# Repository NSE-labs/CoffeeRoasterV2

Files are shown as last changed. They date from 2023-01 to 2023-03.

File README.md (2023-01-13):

# CoffeeRoasterV2

This project is a redesign of the coffee roaster controls that were implemented over a decade ago. In that previous design, the low level control circuits were installed within the coffee roaster itself. Years of operation in the elevated temperatures combined with dust from the roasting process have made maintenance of the circuits difficult at best, not to mention the tight fit of these circuits within the roaster.

For more information, check out the Documentation directory of this project.

Note that the Node Red software for this project resides in a separate GitHub repository (*CoffeeRoasterV2NodeRed*). This allows use of the Node Red Project feature to manage the Node Red code through Git/Github. The Git repository for that code resides on the Atomic Pi and so is separate from this repository.

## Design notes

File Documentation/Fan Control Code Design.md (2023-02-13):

# Arduino code design for fan control
## Overview
The main fan on the coffee roaster is driven by a triac circuit that is controlled by the Arduino software to vary the speed of the fan, based on the user-controlled fan setting (0-100%). In the original version of the coffee roaster controls the heater was also controlled this way, but in Version 2 the heater is now controlled by a Solid State Relay.

There are two signal lines between the triac circuit and the Arduino processor, Zero Crossing Detect and Trigger Triac.
```mermaid
sequenceDiagram
    Triac Circuit->>Processor: Zero Crossing Detect
    Processor->>Triac Circuit: Trigger Triac
```
The Zero Crossing Detect is driven by the AC line voltage going to the triac circuit. The AC line voltage is a sine wave with a frequency of 60 Hz in North America. Each time the voltage passes through zero (each half cycle of the sine wave) the Zero Crossing Detect signal is triggered. When the processor sees this signal it starts a count which is based on the fan setting (0-100%). When the count expires the processor pulses the Trigger Triac signal which turns the triac on, thus supplying voltage and current to the fan motor. Once the triac is triggered it will stay latched on until the AC line voltage reaches zero again - the next zero crossing (that's just the way triacs work - once triggered they stay on until the supply voltage goes to zero). The longer the delay (up to one half cycle) between Zero Crossing Detect and Trigger Triac, the less of each AC cycle will be supplied to the fan motor, and the slower it will go. This is repeated each half cycle of the AC line voltage, or 120 times per second.
## Details of the implementation
The Arduino processor (Atmel ATmega328) has a number of built-in hardware features in addition to the processor core. This includes
- The ability for an external signal to interrupt the software execution and cause it to vector to an interrupt service routine (external interrupt).
- A 16-bit timer/counter (Timer 1) with two compare registers that can be used to drive an external signal when the timer reaches the count loaded into the compare register.

The triac circuit is connected to the processor as follows:

|Signal|Pin Direction|Arduino Pin|Processor Pin|Function|
|-|:-:|:-:|:-:|-|
|Zero Crossing Detect|Input|D2|PD2|External Interrupt 0 (INT0)|
|Trigger Triac|Output|D9|PB1|Timer/Counter1 output compare match A output (OC1A)|
| | | | | |

Timer 1 is initialized as listed in the following table. Please refer to the [ATmega328 datasheet](https://ww1.microchip.com/downloads/en/DeviceDoc/Atmel-7810-Automotive-Microcontrollers-ATmega328P_Datasheet.pdf) for a thorough description of the Timer 1 registers.
|Register|Value|Setting|
|-|-|-|
|TCCR1A|B01000000|Trigger Triac (OC1A) signal toggles on comparator match, timer set to normal counting mode (not PWM). The initialization code also ensures that the OC1A output signal is initialized to zero (logic low).|
|TCCR1B|B00000010|No capture filtering (input capture isn't used in this design), timer set to normal counting mode (not PWM), the clock prescaler is set to clk/8. The Arduino system clock frequency is 16 MHz so in this case the timer clock is set to 16 MHz/8 = 2 MHz or 0.5 microseconds per count.|
|TIMSK1|B00000010|Compare A interrupt enabled. An interrupt will occur when the timer reaches the value in the compare register (OCR1A).|
| | | 

The sequence of operation is as follows:
1. When a zero crossing is detected the External Interrupt 0 (Zero Crossing Detect) interrupt service routine sets the timer count (TCNT1) register to zero and sets the output compare register (OCR1A) to the target timer count at which it will turn on the Trigger Triac signal and cause an interrupt. It gets this target timer count from a lookup table where the index is the desired fan setting (0-100%) and the output is the target count.
2. The timer then counts up at 0.5 microseconds per count until it reaches the target value stored in the compare register (OCR1A). This causes the Trigger Triac (OC1A) signal to turn on (logic high) and the timer compare A interrupt to occur.
3. The timer compare A interrupt service routine waits for a brief period to provide the minimum pulse width to trigger the triac, then turns off the Trigger Triac signal (logic low). The cycle then repeats at step 1.

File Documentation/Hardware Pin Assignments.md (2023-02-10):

# NSE Coffee Roaster V2
## Hardware Pin Assignments
----
### Arduino Nano
| Digital Pin | Connection | I/O |
| --- | --- | --- |
| 0 | Serial Receive Data | Input |
| 1 | Serial Transmit Data | Output |
| 2 | Zero Crossing Detect (INT0) | Input |
| 3 | Roaster Drum Motor On/Off | Output |
| 4 | Roaster Case Fan On/Off | Output |
| 5 | MAX 6675 D0 | Input |
| 6 | MAX 6675 CS | Output |
| 7 | MAX 6675 CLK | Output |
| 8 | Open | |
| 9 | Fan Triac Trigger | Output |
| 10 | Heater SSR On/OFF | Output |
| 11 | Front Panel LED - Manual | Output |
| 12 | Front Panel LED - Computer | Output |
| 13 | On-board LED | Output |

| Analog Pin | Connection | I/O |
| --- | --- | --- |
| A0 | Heater Front Panel Pot | Input |
| A1 | Fan Front Panel Pot | Input |
| A3 | Open | |
| A4 | I2C Display Interface | Output |
| A5 | I2C Display Interface | Output |
----
### Front Panel Interface Ribbon Cable
| Cable Pin | Signal |
| --- | --- |
| 1 | VCC (+5V) |
| 2 | Ground |
| 3 | Display Pin 4 |
| 4 | Display Pin 3 |
| 5 | Heater Pot |
| 6 | Fan Pot |
| 7 | NC |
| 8 | LED - Manual |
| 9 | NC |
| 10 | LED - Computer |

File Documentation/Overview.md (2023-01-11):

# Coffee Roaster V2
## Background
This project is a redesign of the coffee roaster controls that were implemented over a decade ago. In that previous design, the low level control circuits were installed within the coffee roaster itself. Years of operation in the elevated temperatures combined with dust from the roasting process have made maintenance of the circuits difficult at best, not to mention the tight fit of these circuits within the roaster.

## Project Goals
The idea for this project is to move all of the control circuitry to an external enclosure, and to update where it makes sense to more modern components. Adding a built-in touch panel display to do the high level control functions is also desirable.

## Design

The first challenge this presents is the interface between the coffee roaster and the external enclosure. There are several high voltage and in some cases high current connections that need to be made. Obviously it would be good to keep this interface as simple as possible and not have a multitude of connections to make between the roaster and the electronics enclosure. Luckily a connector set was found at the Huntsville Hamfest that is pretty much ideal for this.

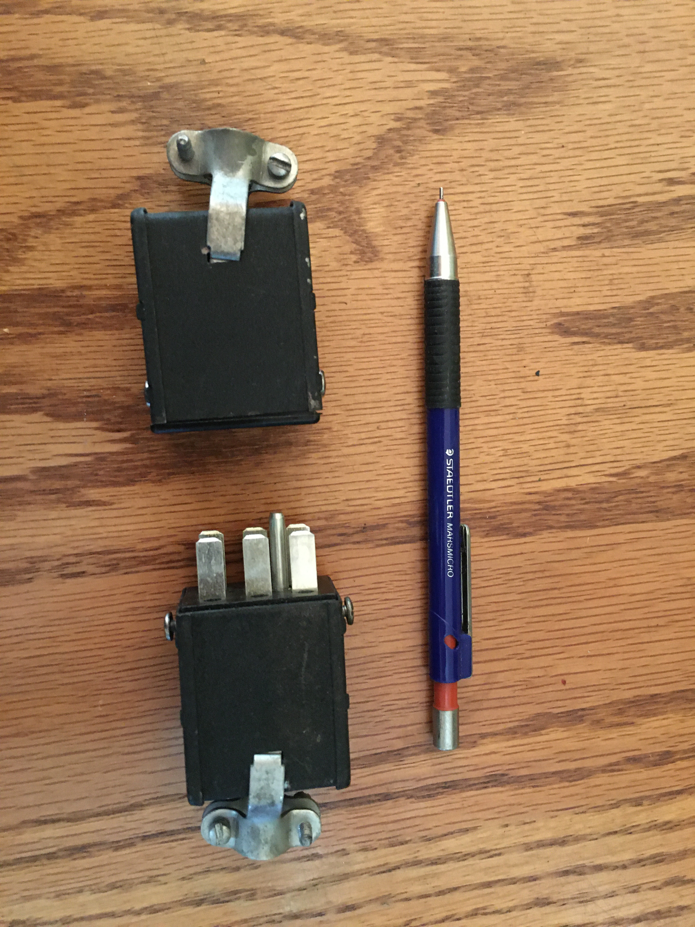
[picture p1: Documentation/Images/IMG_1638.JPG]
[](./Images/IMG_1638.JPG)

This connector should allow us to have only two connections between the roaster and enclosure, this connector and a thermocouple to measure the temperature of the roaster.

The pins of these connections are assigned as follows.

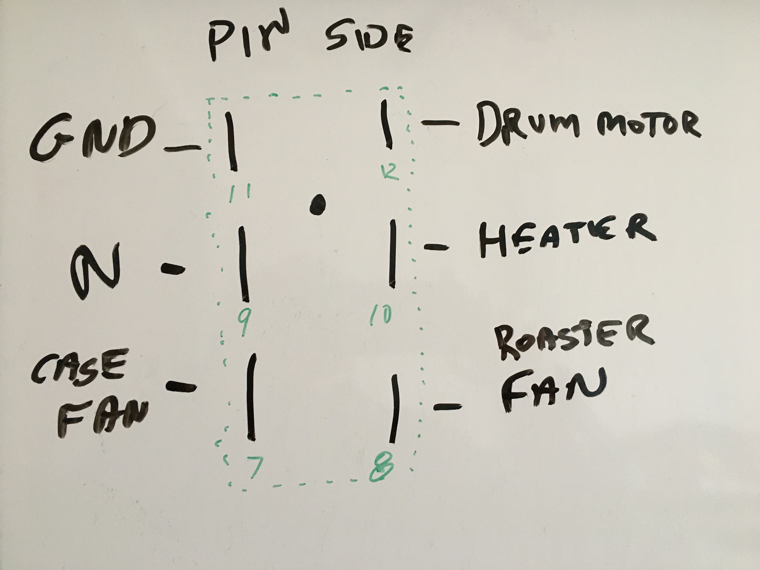
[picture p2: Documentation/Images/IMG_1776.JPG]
[](./Images/IMG_1776.JPG)

Notice that the pins are numbered 7-12. These numbers are molded into the connectors next to the pins. I have no idea why they chose 7-12 as the pin numbers, I can only assume there was another connector with pins 1-6.

You can also see the locating pin on the connector. I originally thought this would be a ground pin as would be the case in a standard 3-prong US outlet. That is not the case however. The male connector has a connection for that pin but it is not connected to anything on the female connector. I connected it to ground in any case.

I included connections for the roaster drum motor and case fan. In the previous design these were always on whenever the roaster was powered. This will give us the capability to control these functions if desired.

The roaster was then modified to remove the previous control circuitry and install wire the new connector.

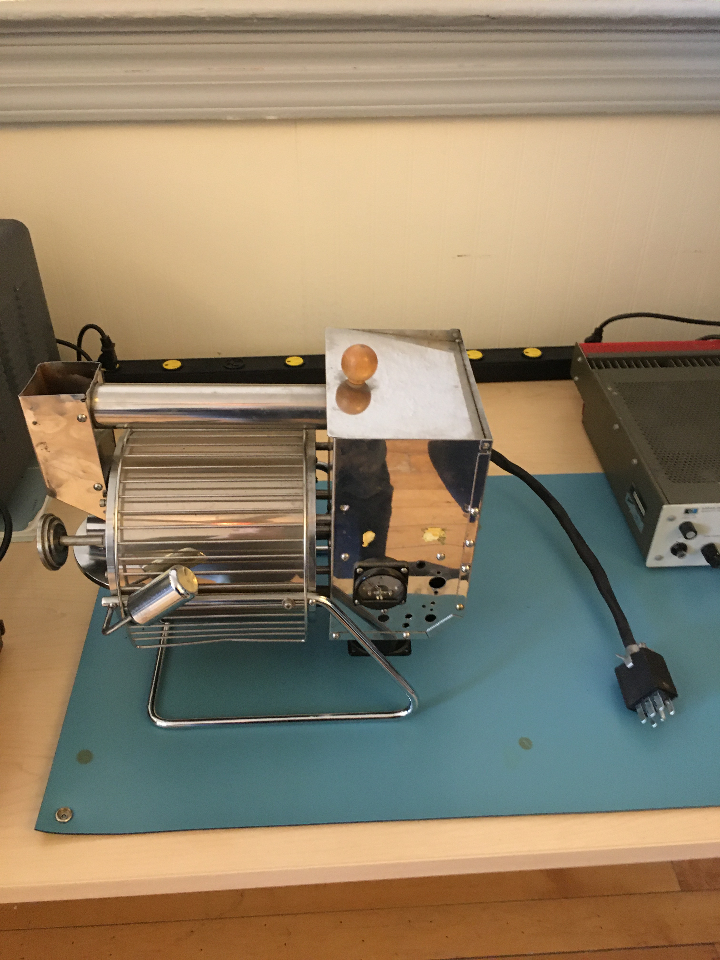
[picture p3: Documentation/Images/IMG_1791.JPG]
Newly Modified Roaster


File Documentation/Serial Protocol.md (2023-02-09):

| | | | | |
|-|-|-|-|-|
|Coffee Roaster Serial Protocol| | | | |
| | | | | |
|Commands are sent to the Arduino. Responses come from the Arduino.| | | | |
|A response is sent after every command.|| | | | |
|A command to set the heater or fan value is ignored and no response is sent if the command mode is Manual|| | | | |
| | | | | |
| | |Serial  Characters|Description| |
|Command|Set control mode|:|Start character| |
| | |>|Set command| |
| | |C or M|Computer or Manual| |
| | |/|End character| |
| | | | | |
|Response|Control mode|:|Start character| |
| | |C or M|Computer or Manual| |
| | |/|End character| |
| | | | | |
|Response|Unknown command|:|Start character|For any unrecognized command|
| | |U|Unknown| |
| | |/|End character| |
| | | | | |
|Command|Read control mode|:|Start character| |
| | |?|Read command| |
| | |C|Control mode| |
| | |/|End character| |
| | | | | |
|Response|Control mode|See above| | |
| | | | | |
|Command|Read temperature|:|Start character| |
| | |?|Read command| |
| | |T|Temperature| |
| | |/|End character| |
| | | | | |
|Response|Temperature|:|Start character| |
| | |T|Temperature| |
| | |0-9|Digit 1|Temperature in degrees C|
| | |0-9|Digit 2| |
| | |0-9|Digit 3| |
| | |.|Decimal point| |
| | |0-9|Digit 4| |
| | |0-9|Digit 5| |
| | |/|End character| |
| | | | | |
|Command|Set Heater|:|Start character| |
| | |>|Set command| |
| | |H|Heater| |
| | |0-9|Digit 1|0-100%|
| | |0-9|Digit 2| |
| | |0-9|Digit 3| |
| | |/|End character| |
| | | | | |
|Response|Heater Value|:|Start character| |
| | |H|Heater| |
| | |0-9|Digit 1|0-100%|
| | |0-9|Digit 2| |
| | |0-9|Digit 3| |
| | |/|End character| |
| | | | | |
|Command|Read Heater|:|Start character| |
| | |?|Read command| |
| | |H|Heater| |
| | |/|End character| |
| | | | | |
|Response|Heater Value|See above| | |
| | | | | |
|Command|Set Fan|:|Start character| |
| | |>|Set command| |
| | |F|Fan| |
| | |0-9|Digit 1|0-100%|
| | |0-9|Digit 2| |
| | |0-9|Digit 3| |
| | |/|End character| |
| | | | | |
|Response|Fan Value|:|Start character| |
| | |F|Fan| |
| | |0-9|Digit 1|0-100%|
| | |0-9|Digit 2| |
| | |0-9|Digit 3| |
| | |/|End character| |
| | | | | |
|Command|Read Fan|:|Start character| |
| | |?|Read command| |
| | |F|Fan| |
| | |/|End character| |
| | | | | |
|Response|Fan Value|See above| | |
| | | | | |
|New commands added for V2|
|Command|Drum motor on/off|:|Start character| |
| | |>|Set command| |
| | |+ or -|On(+) or Off(-)| |
| | |/|End character| |
| | | | | |
|Response|Drum motor status|:|Start character| |
| | |+ or -|On(+) or Off(-)| |
| | |/|End character| |
| | | | | |
|Command|Read drum motor status|:|Start character| |
| | |?|Read command| |
| | |D|Drum motor| |
| | |/|End character| |
| | | | | |
|Response|Drum motor status|See above| | |
| | | | | |
|Command|Case fan on/off|:|Start character| |
| | |>|Set command| |
| | |^ or #|On(^) or Off(#)| |
| | |/|End character| |
| | | | | |
|Response|Case fan status|:|Start character| |
| | |^ or #|On(^) or Off(#)| |
| | |/|End character| |
| | | | | |
|Command|Read case fan status|:|Start character| |
| | |?|Read command| |
| | |A|Case fan|A for Airflow|
| | |/|End character| |
| | | | | |
|Response|Case fan status|See above| | |
| | | | | |
| | | | | |

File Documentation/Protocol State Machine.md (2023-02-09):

# NSE Coffee Roaster V2
## Serial protocol state machine (Arduino)

```mermaid
  stateDiagram-V2
      [*] --> BetweenMessages
      BetweenMessages --> StartReceived : Semicolon
      BetweenMessages --> UnknownCommand : Not Semicolon
      UnknownCommand --> BetweenMessages
      StartReceived --> SetReceived : >
      StartReceived --> ReadReceived : ?
      StartReceived --> UnknownCommand : Not > or ?
      SetReceived --> CommandReceived : Valid set command other than H or F
      SetReceived --> Digit1 : H or F
      SetReceived --> UnknownCommand : Not valid set command
      Digit1 --> Digit2
      Digit2 --> Digit3
      Digit3 --> CommandReceived
      CommandReceived --> SendResponse : /
      CommandReceived --> UnknownCommand : Not /
      SendResponse --> BetweenMessages
      ReadReceived --> CommandReceived : Valid read command
      ReadReceived --> UnknownCommand : Not valid read command

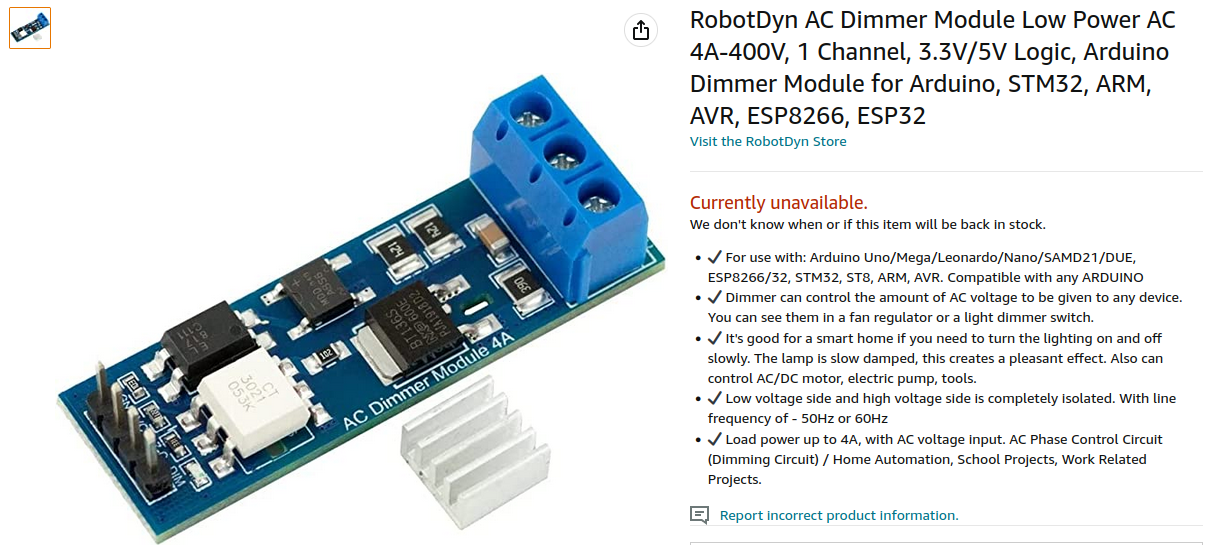
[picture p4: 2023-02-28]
Documentation/Datasheets/Fan dimmer module.png

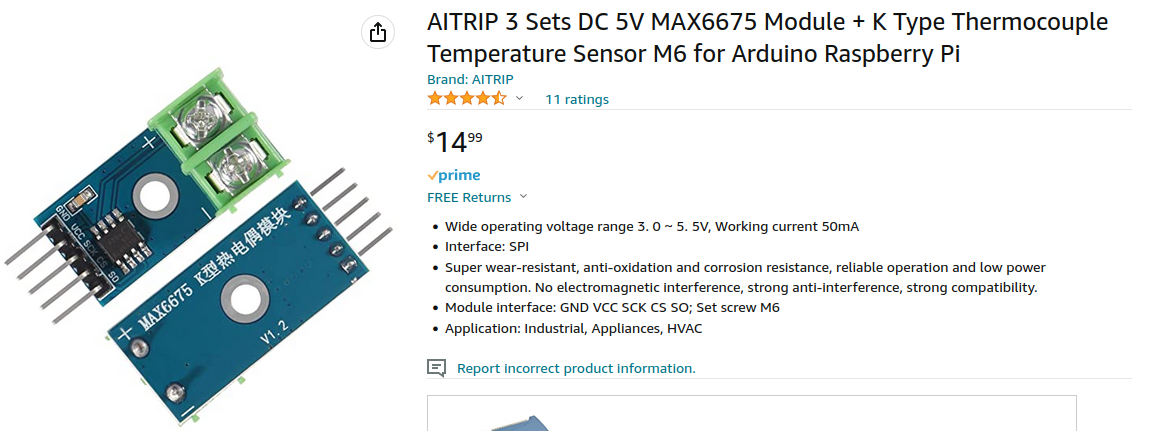
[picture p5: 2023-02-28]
Documentation/Datasheets/MAX6675 board.png

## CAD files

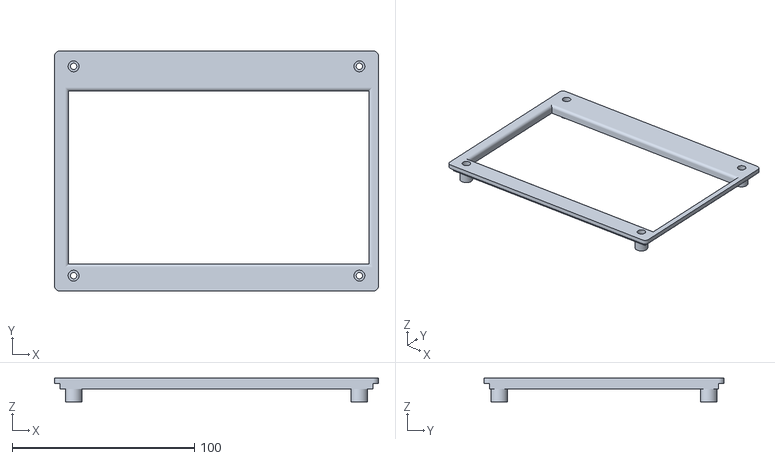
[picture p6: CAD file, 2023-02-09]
FreeCAD/Large Display Mount-Front Face.stl
178.0 x 132.0 x 13.0

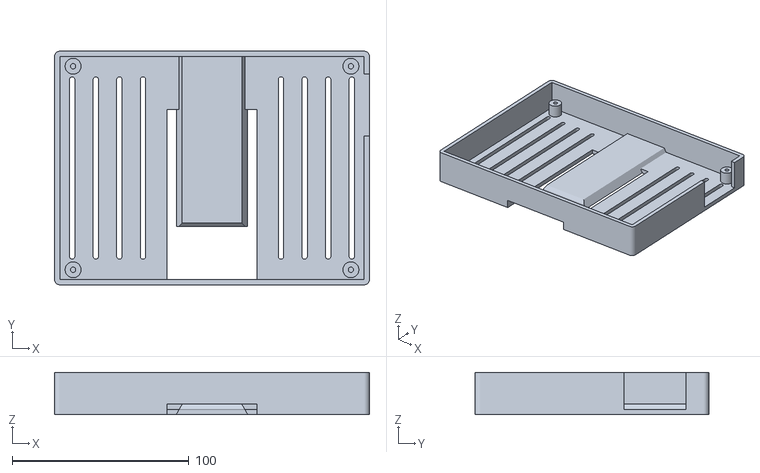
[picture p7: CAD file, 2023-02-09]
FreeCAD/Large Display Mount-Body.stl
178.0 x 132.0 x 24.0

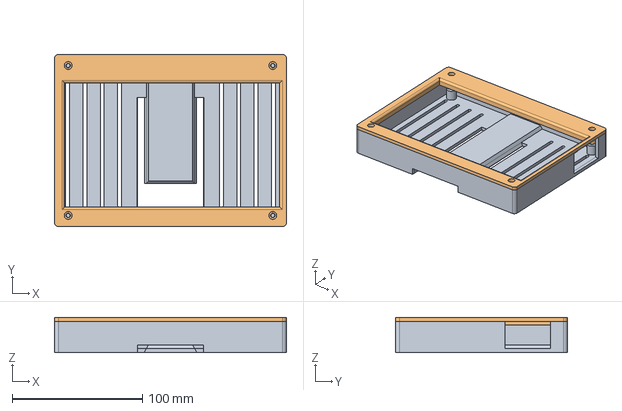
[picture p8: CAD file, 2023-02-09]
FreeCAD/Large Display Mount.FCStd
178.0 x 132.0 x 27.0 mm
Front Face

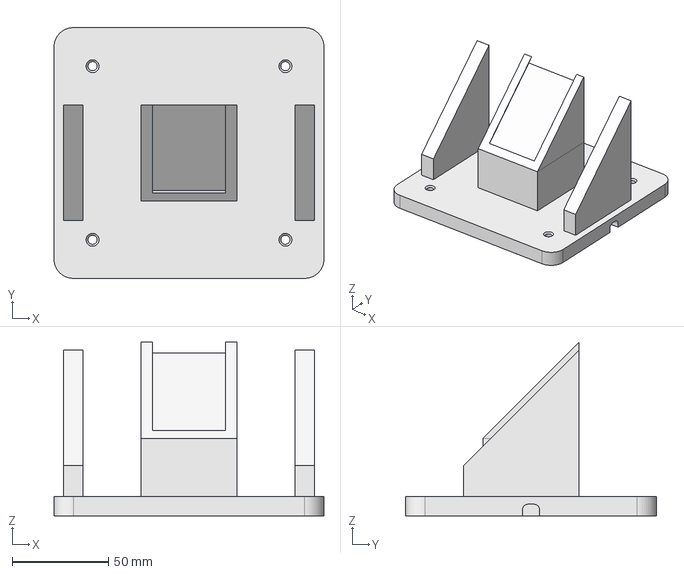
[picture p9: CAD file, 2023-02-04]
FreeCAD/Large Display Mount Base.FCStd
140.0 x 130.0 x 90.0 mm

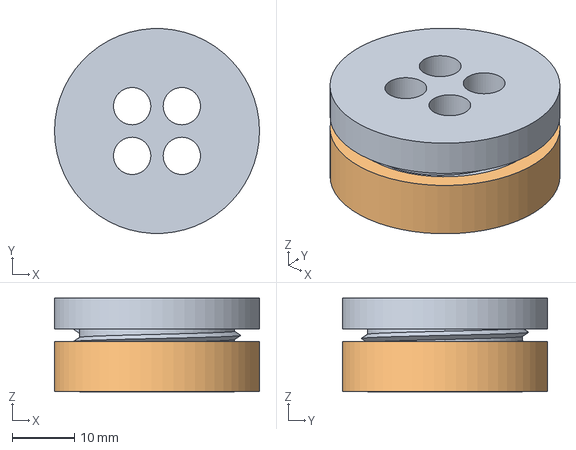
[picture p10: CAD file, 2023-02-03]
FreeCAD/Hole Cover.FCStd
33.0 x 33.0 x 15.1 mm
Screw
Nut

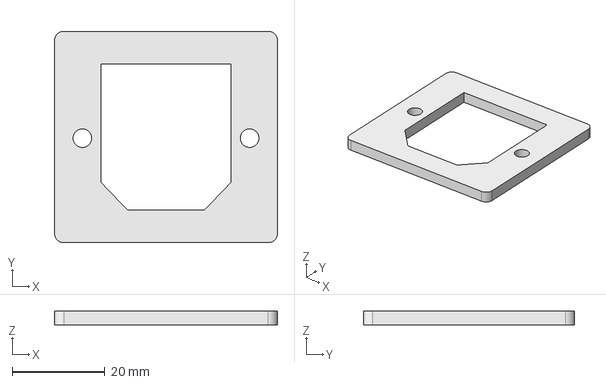
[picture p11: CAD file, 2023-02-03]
FreeCAD/AC Inlet Backing Plate.FCStd
48.0 x 45.5 x 3.00 mm

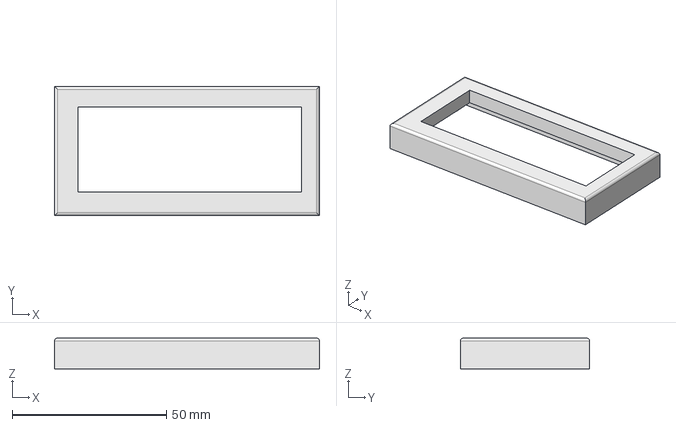
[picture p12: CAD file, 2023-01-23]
FreeCAD/Small Display Cover.FCStd
86.0 x 42.0 x 10.0 mm

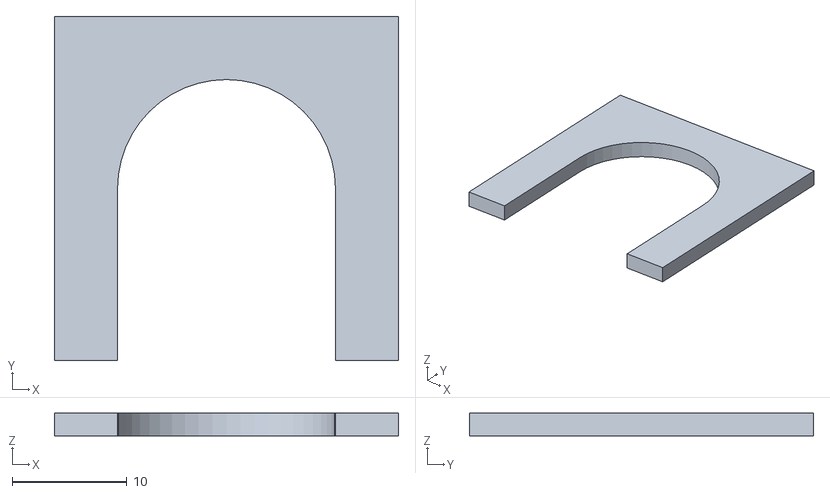
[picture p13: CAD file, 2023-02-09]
FreeCAD/Cable clamp washer-Body.stl
30.0 x 30.0 x 2.00

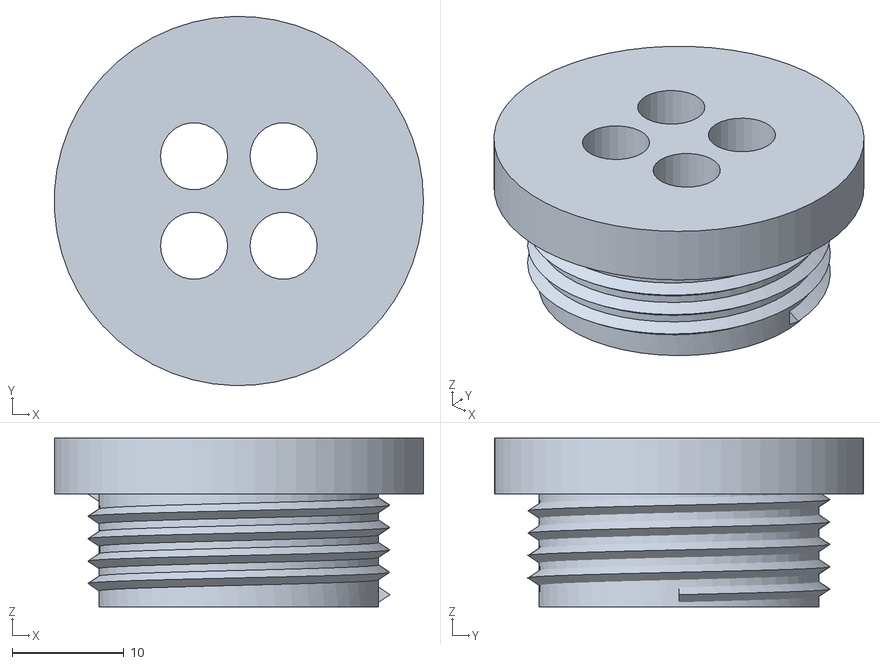
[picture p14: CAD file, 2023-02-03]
FreeCAD/Hole Cover-Screw.stl
33.0 x 33.0 x 15.1

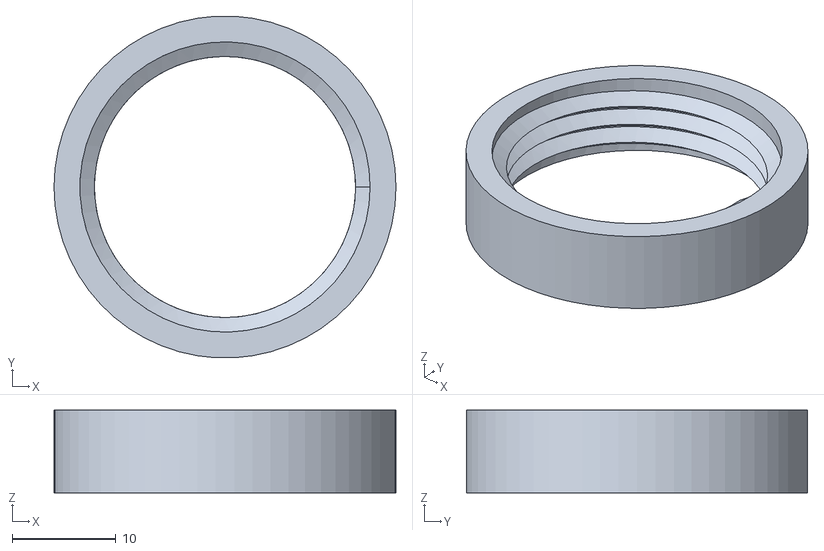
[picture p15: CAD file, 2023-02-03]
FreeCAD/Hole Cover-Nut.stl
33.0 x 33.0 x 8.00

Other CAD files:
FreeCAD/Large Display Mount Base-Body.stl
FreeCAD/AC Inlet Backing Plate-Body.stl
FreeCAD/Small Display Cover-Body.stl
FreeCAD/Cable clamp washer.FCStd

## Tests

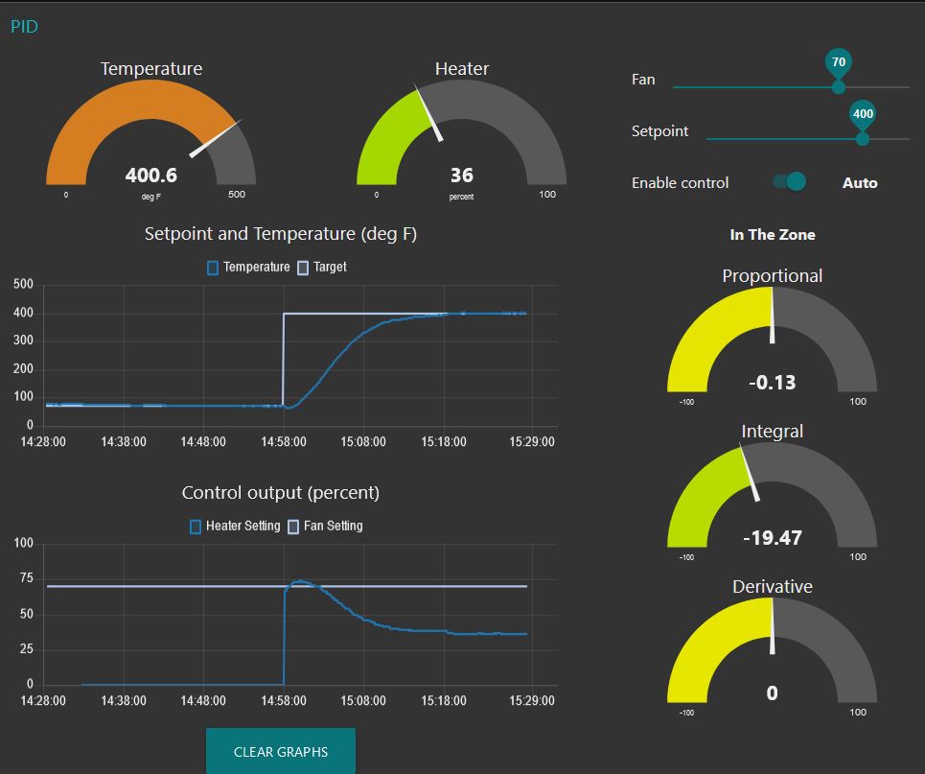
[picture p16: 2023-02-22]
PID tuning/Trial 3/PID Screen.JPG

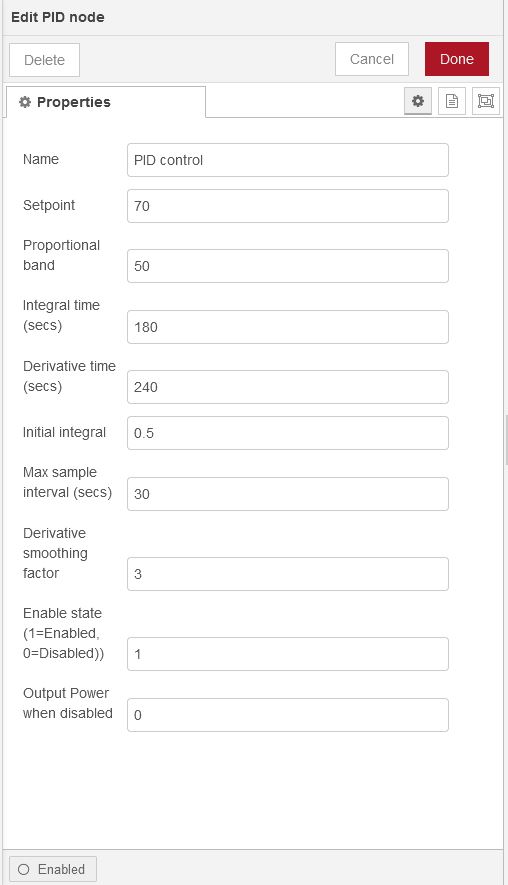
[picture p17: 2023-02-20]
PID tuning/Trial 1/PID settings.JPG

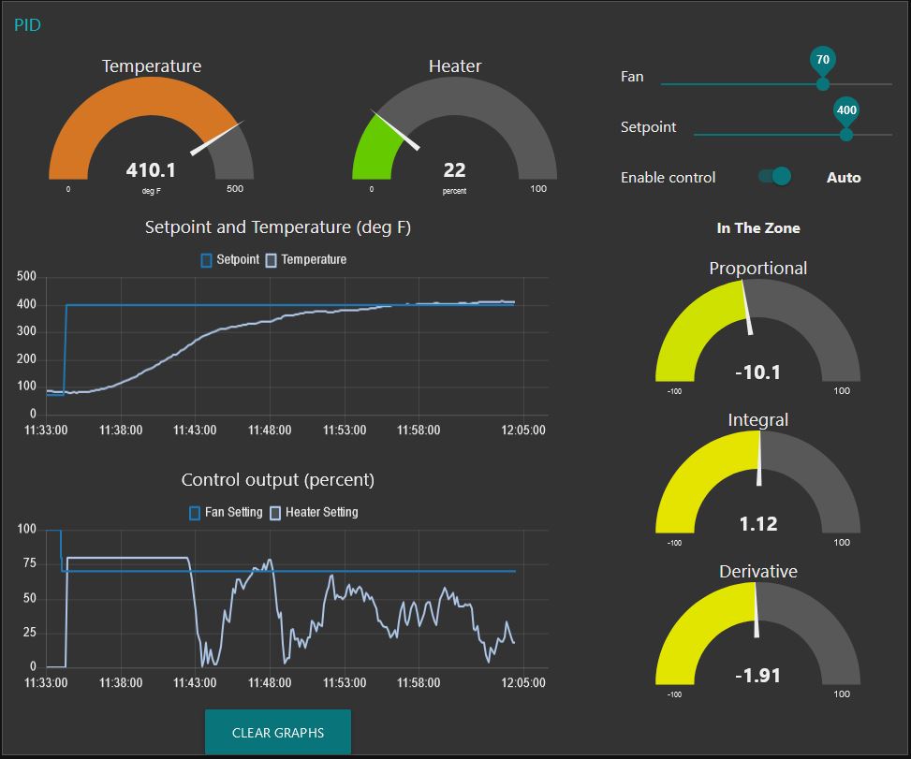
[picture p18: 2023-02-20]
PID tuning/Trial 1/PID screen.JPG

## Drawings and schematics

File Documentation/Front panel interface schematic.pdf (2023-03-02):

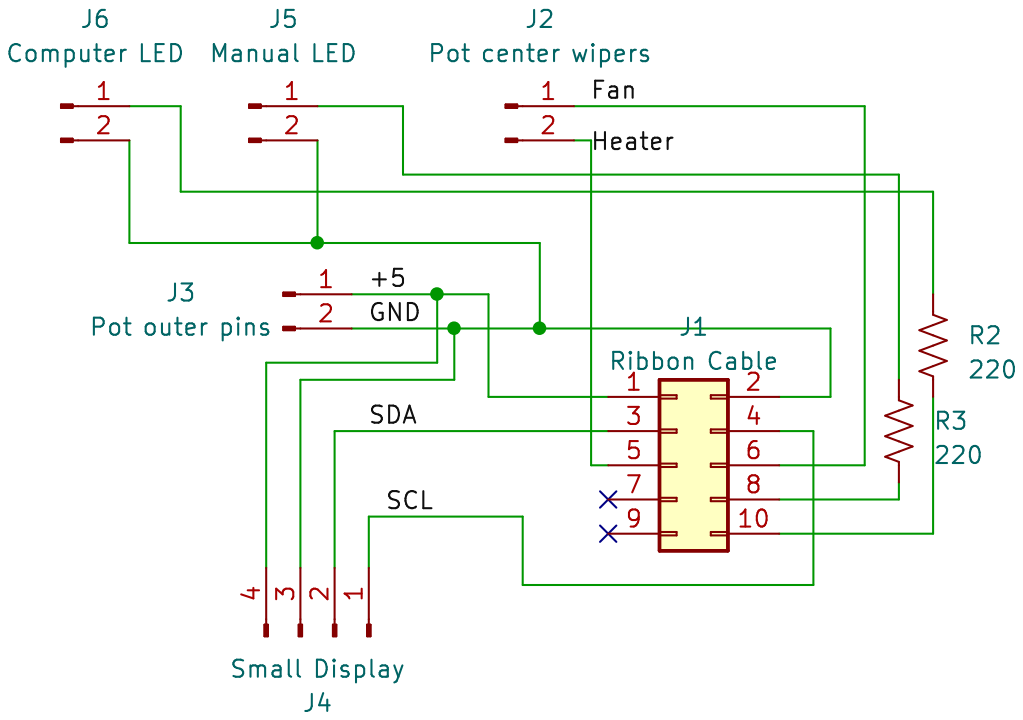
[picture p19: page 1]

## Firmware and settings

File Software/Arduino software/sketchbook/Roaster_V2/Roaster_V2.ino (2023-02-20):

// NSE Coffee Roaster code for the Arduino Uno
// 2011 NSE Labs
// Version 2 2023 NSE Labs
// This code is in the public domain - feel free to use as you see fit
//
// MAX 6675 library is the Adafruit version available in Manage Libraries in the Arduino IDE
//
// PString library from Mikal Hart http://arduiniana.org/libraries/PString/
// 

#include <max6675.h>
#include <PString.h>
#include <Wire.h>
#include <avr/io.h>
#include <avr/interrupt.h>

// Digital I/O pins we are using
#define ZERO_CROSSING_DETECT_INPUT 2
#define DRUM_MOTOR 3
#define CASE_FAN 4
#define MAX6675_DO_INPUT 5
#define MAX6675_CS_OUTPUT 6
#define MAX6675_CLK_OUTPUT 7
#define FAN_TRIAC_OUTPUT 9
#define HEATER_SSR_OUTPUT 10
#define MANUAL_LED_OUTPUT 11
#define COMPUTER_LED_OUTPUT 12
#define ONBOARD_LED_OUTPUT 13

// Analog I/O pins we are using
#define HEATER_CONTROL_POT 0
#define FAN_CONTROL_POT 1
#define I2C_SDA A4
#define I2C_CLK A5

// Fire up the MAX 6675 thermocouple interface library
MAX6675 thermocouple(MAX6675_CLK_OUTPUT, MAX6675_CS_OUTPUT, MAX6675_DO_INPUT);

//********************************************************************
// These are the main parameters we are reading/setting on the roaster
//********************************************************************
double temperature = 0; // Roaster temperature degrees C
int heater = 0;  // Roaster heater output 0-100%
int fan = 0;     // Roaster fan output 0-100%
//********************************************************************
// We can also turn these values on/off
//********************************************************************
enum OnOff {
  on = 1,
  off =0
};

OnOff drumMotor = off;
OnOff caseFan = on;


// The control mode can be manual or computer. In manual
// mode the front panel knobs on the roaster are used to 
// control the power to the heater and the fan speed. In 
// computer mode the front panel knobs are disabled and 
// the heater and fan are controlled by serial commands
// from the PC through the USB port
enum mode {
  manual,
  computer
} controlMode = manual;

// Serial port receive state
// See state diagram on the NSE web site
enum state {
   betweenMessages,
   startReceived,
   setReceived,
   digit1,
   digit2,
   digit3,
   readReceived,
   commandReceived
} rcvState = betweenMessages;

// These are the commands we will accept from the PC
enum command {
  unknown,
  setControlMode,
  readControlMode,
  readTemperature,
  setHeater,
  readHeater,
  setFan,
  readFan,
  setDrum,
  readDrum,
  setCaseFan,
  readCaseFan
} rcvCommand = unknown;

// temporary storage during numeric commands
char firstDigit = 0;
char secondDigit = 0;
char thirdDigit = 0;
  
// Serial response for unknown command
const char *unknownCommand = ":U/";

#define TEMP_SAMPLE_PERIOD  1000 // how long between temperature samples in milliseconds
long lastTempSampleTime = 0;  // last time the temperature was sampled

#define DISPLAY_UPDATE_PERIOD 100 // how long between display updates in milliseconds
long lastDisplayUpdateTime = 0; // last time display was updated

#define HEATER_CYCLE_TIME 5000 // In milliseconds. The heater will be turned on for a percentage of this time
long lastHeaterCycleTime = 0; // and off for the remainder of this time, based on the heater % setting.

#define TRIGGER_PULSE_COUNT 80  // The triac trigger must stay high for this number of timer1 counts (40 uS)

// Map setting (0-100%)to timer counts for triac firing
unsigned int fanMap[101] = 
{ 
  0xffff,9600,9599,9596,9593,9588,9583,9577,9569,9561,
  9552,9542,9531,9519,9506,9492,9477,9461,9444,9427,
  9408,9388,9368,9346,9324,9301,9277,9252,9226,9199,
  9171,9142,9113,9082,9051,9019,8986,8952,8917,8881,
  8845,8807,8769,8730,8690,8649,8607,8564,8521,8476,
  8431,8384,8337,8289,8240,8190,8139,8087,8034,7980,
  7926,7870,7813,7755,7696,7636,7575,7512,7449,7384,
  7318,7251,7182,7112,7041,6968,6894,6818,6741,6661,
  6580,6497,6412,6325,6236,6144,6050,5953,5854,5751,
  5645,5535,5421,5303,5180,5052,4917,4776,4627,4469,
  4300
};

int ledState = LOW;  // used for toggling the on-board LED
int currentFanOutput = 0; // used to ramp the fan output to its set level
#define FAN_UPDATE_INTERVAL 34 // how many milliseconds between fan output updates of 1% change
long lastFanUpdateTime = 0; // last time the fan output was updated

   
void setup() 
{
  // start serial port at 115200 bps:
  Serial.begin(115200);
  
  // Initialize drum motor and case fan outputs - NOTE: they are active low
  pinMode(DRUM_MOTOR, OUTPUT); 
  digitalWrite(DRUM_MOTOR, HIGH); /* drum motor off */
  pinMode(CASE_FAN, OUTPUT); 
  digitalWrite(CASE_FAN, LOW); /* case fan on */
  
  // Set up the LEDs
  pinMode(ONBOARD_LED_OUTPUT, OUTPUT);
  pinMode(MANUAL_LED_OUTPUT, OUTPUT);
  pinMode(COMPUTER_LED_OUTPUT, OUTPUT);
  setFrontPanelLEDs();

  // Set up the port pin for zero crossing detect
  pinMode(ZERO_CROSSING_DETECT_INPUT, INPUT);
  digitalWrite(ZERO_CROSSING_DETECT_INPUT, HIGH);  // Turn on the pullup resistor  
  
  // Set up the analog input ports (used for front panel knobs)
  pinMode(A0, INPUT);
  pinMode(A1, INPUT);
  digitalWrite(A0, LOW);  // Turn off the pullup resistors
  digitalWrite(A1, LOW);
  
  // Wait for MAX 6675 to stabilize
  delay(500);

  pinMode(HEATER_SSR_OUTPUT, OUTPUT);  // Set the heater solid state relay pin to output
  
  // Set up Timer 1 for triac control of the fan
  TIMSK1 = B00000000;  //No interrupts enabled
  TCCR1A = B10000000;  //OC1A output pin set to zero on comparator match, timer set to Normal mode
  TCCR1B = B00000010;  //No capture filtering, timer set to Normal mode, use clk/8 prescaler 
  OCR1A = 0xffff;  // Set the compare register to its maximum value
  TCNT1 = 0;  //Set the timer count to zero
  TCCR1C = B10000000;  //Force a compare match on comparator A to set the output to zero
  TIMSK1 = B00000010;  //Compare A and Compare B interrupts enabled
  pinMode(FAN_TRIAC_OUTPUT, OUTPUT);  // Set the fan triac trigger pin to output
  TCCR1A = B01000000;  //Comparator A output pin toggles on comparator match, timer set to Normal mode


  // Set up the zero crossing interrupt
  attachInterrupt(0, zeroCrossingInterrupt, FALLING);

  // start the I2C display interface and put some text on the screen
  initializeDisplay();
}

// Interrupt service routine for zero crossing detection
void zeroCrossingInterrupt()
{
  TCNT1 = 0;  //Set the timer count to zero
   
  // Set the counter compare registers based on the heater and fan settings
  OCR1A = fanMap[currentFanOutput];
}

// Interrupt service routine for comparator A match
ISR(TIMER1_COMPA_vect)
{
  unsigned int start;
  
  start = TCNT1;  // Read the current timer value
  while((TCNT1 - start) < TRIGGER_PULSE_COUNT); // Wait for the required trigger time for the triac
  
  TCCR1C = B10000000;  // Force a compare match on channel A to toggle the output pin to zero
}

void loop() 
{ 
  long currentMillis;
  int heaterOnTime;
  int analogValue;

  currentMillis = millis();

  if(controlMode == manual)
  {
    // Read the front panel control knobs - heater and fan controls
    // With the longer cables to the front panel on V2 hardware, there is a slight voltage 
    // sag near the maximum A/D value (1023 = +5 V). Make sure that the pot can go all the
    // way to 100% by treating all A/D counts above a threshold as 100%. 
    // Also, in V1 hardware the pots were wired so that +5V = 0% and 0V = 100%.
    // This is changed in V2 hardware so that +5V = 100% and 0V = 0%.
    
    analogValue = analogRead(HEATER_CONTROL_POT);
    if(analogValue > 1003) analogValue = 1023; // compensate for any voltage sag
    heater = map(analogValue, 0, 1023, 0, 100);

    analogValue = analogRead(FAN_CONTROL_POT);
    if(analogValue > 1003) analogValue = 1023; // compensate for any voltage sag
    fan = map(analogValue, 0, 1023, 0, 100);

    // While in manual mode, if the heater is turned on then start the drum 
    // rotating. This allows operation of the roaster even if the external
    // computer fails (otherwise we are dependent on serial commands to start
    // the drum rotating). The heater is considered turned on if the setting
    // is greater than 2%. This prevents noise from turning on the drum.
    if((heater > 2) && (drumMotor == off))
    {
      drumMotor = on;
      digitalWrite(DRUM_MOTOR, LOW); /* drum motor on (active low) */
    }
  }    
    
  // read the temperature every TEMP_SAMPLE_PERIOD
  if((currentMillis - lastTempSampleTime) > TEMP_SAMPLE_PERIOD) 
  {
    // save the last time we took a sample and read the temperature
    lastTempSampleTime = currentMillis;   
    temperature = thermocouple.readCelsius();
 
    // toggle the LED to show we are sampling
    if(ledState == LOW)
    {
      ledState = HIGH;      
    }
    else
    {
      ledState = LOW;
    }
    digitalWrite(ONBOARD_LED_OUTPUT, ledState);
    
  }
  
  // deal with any commands from the PC
  if (Serial.available() >  0) handleSerial();  
  
  // update the fan output every FAN_UPDATE_INTERVAL milliseconds
  if((currentMillis - lastFanUpdateTime) > FAN_UPDATE_INTERVAL) 
  {
    lastFanUpdateTime = currentMillis;
    
    // ramp the fan output to its set value by 1% per interval
    if(currentFanOutput < fan)
    {
      currentFanOutput += 1;
    }
    else if (currentFanOutput > fan)
    {
      currentFanOutput -= 1;
    }
  }

  // Heater Proportional Control
  // cycle the heater every HEATER_CYCLE_TIME milliseconds
  if((currentMillis - lastHeaterCycleTime) > HEATER_CYCLE_TIME) 
  {
    lastHeaterCycleTime = currentMillis;
    heaterOnTime = (HEATER_CYCLE_TIME * heater)/100;
  }

  if((currentMillis - lastHeaterCycleTime) < heaterOnTime)
  { /* heater is on during the first part of the cycle */
    digitalWrite(HEATER_SSR_OUTPUT, HIGH);
  }
  else
  { /* heater is off during the second part of the cycle */
    digitalWrite(HEATER_SSR_OUTPUT, LOW);
  }
  
  if(currentMillis > 3000)
  {
    // Leave the initial message up for 3 seconds, after that put data on the display

    // update the display every DISPLAY_UPDATE_PERIOD
    if((currentMillis - lastDisplayUpdateTime) > DISPLAY_UPDATE_PERIOD)
    {
      lastDisplayUpdateTime = currentMillis;
      updateDisplay();
    }
  }
   
}

void handleSerial()
{
      // This routine is called each time a serial character is available
      // It runs the serial receive state machine documented in the project documentation

      char inByte; // incoming serial byte
      int number;  // decoded number for numeric commands       
      
      inByte = Serial.read();
      switch(rcvState) 
      {
        case betweenMessages:
          if(inByte == ':')
          {
            rcvState = startReceived;
          } 
          else
          {
            clearState();
          }
          break;
        case startReceived:
          if(inByte == '>')
          {
            rcvState = setReceived;
          }
          else if(inByte == '?')
          {
            rcvState = readReceived;
          }
          else
          {
            Serial.print(unknownCommand);
            clearState();
          } 
          break;
        case readReceived:
          switch(inByte)
          {
            case 'C':  // read command mode
              rcvCommand = readControlMode;
              rcvState = commandReceived;
              break;
            case 'T':  // read temperature
              rcvCommand = readTemperature;
              rcvState = commandReceived;
              break;
            case 'H':   // read heater
              rcvCommand = readHeater;
              rcvState = commandReceived;
              break;
            case 'F':  // read fan 
              rcvCommand = readFan;
              rcvState = commandReceived;
              break;
            case 'D': // read drum motor status
              rcvCommand = readDrum;
              rcvState = commandReceived;
              break;
            case 'A': // read case fan status
              rcvCommand = readCaseFan;
              rcvState = commandReceived;
              break;
            default:
              Serial.print(unknownCommand);
              clearState();
              break;
          }
          break;
        case setReceived:
          switch(inByte)
          {
            case 'C': // set computer control mode
              rcvCommand = setControlMode;
              controlMode = computer;
              setFrontPanelLEDs();
              rcvState = commandReceived;
              break;
            case 'M': // set manual mode
              rcvCommand = setControlMode;
              controlMode = manual;
              setFrontPanelLEDs();
              rcvState = commandReceived;
              break;
            case 'H':
              if(controlMode == manual)
              {
                // Ignore set heater command in manual mode
                clearState();
              }
              else
              {
                rcvCommand = setHeater;
                rcvState = digit1;
              }
              break;
            case 'F':
              if(controlMode == manual)
              {
                // Ignore set fan command in manual mode
                clearState();
              }
              else
              {
                rcvCommand = setFan;
                rcvState = digit1;
              }
              break;
            case '+':
              rcvCommand = setDrum;
              drumMotor = on;
              digitalWrite(DRUM_MOTOR, LOW); /* drum motor on (active low) */
              rcvState = commandReceived;
              break;
            case '-':
              rcvCommand = setDrum;
              drumMotor = off;
              digitalWrite(DRUM_MOTOR, HIGH); /* drum motor off */
              rcvState = commandReceived;
              break;
            case '^':
              rcvCommand = setCaseFan;
              caseFan = on;
              digitalWrite(CASE_FAN, LOW); /* case fan on (active low) */
              rcvState = commandReceived;
              break;
            case '#':
              rcvCommand = setCaseFan;
              caseFan = off;
              digitalWrite(CASE_FAN, HIGH); /* case fan off */
              rcvState = commandReceived;
              break;              
            default:
              Serial.print(unknownCommand);
              clearState();
              break;
          }
          break;
        case digit1:
          if(isanum(inByte))
          {
            firstDigit = inByte;
            rcvState = digit2;
          }
          else
          {
              Serial.print(unknownCommand);
              clearState();
          }
          break;
        case digit2:
          if(isanum(inByte))
          {
            secondDigit = inByte;
            rcvState = digit3;
          }
          else
          {
              Serial.print(unknownCommand);
              clearState();
          }
          break;
        case digit3:
          if(isanum(inByte))
          {
            thirdDigit = inByte;
            rcvState = commandReceived;
            
            firstDigit = firstDigit - '0';  // convert from ASCII to num
            secondDigit = secondDigit - '0';
            thirdDigit = thirdDigit - '0';
            
            number = ((int)firstDigit*100)+((int)secondDigit*10)+(int)thirdDigit;
            if(number > 100) number = 100;
            if(number < 0) number = 0;
            
            switch(rcvCommand)
            {
              case setHeater:
                heater = number;
                break;
              case setFan:
                fan = number;
                break;
            }
          }
          else
          {
              Serial.print(unknownCommand);
              clearState();
          }
          break;
        case commandReceived:
          if(inByte == '/')
          {
            sendResponse();
          }
          else
          {
            Serial.print(unknownCommand);
          }
          clearState();
          break;
        default:
          Serial.print(unknownCommand);
          clearState();
          break;                
      }           
}


char isanum(char c)
{
  // returns 1 if the character is a number, zero otherwise
  switch(c)
  {
    case '0':
    case '1':
    case '2':
    case '3':
    case '4':
    case '5':
    case '6':
    case '7':
    case '8':
    case '9':
      return (1);
      break;
    default:
      return (0);
      break;
  }
}

void clearState()
{
  rcvState = betweenMessages;
  rcvCommand = unknown;
}

void sendResponse()
{
  Serial.print(":"); // Send start character
  switch(rcvCommand)
  {
    case setControlMode:
    case readControlMode:
      if(controlMode == computer)
      {
        Serial.print("C");
      }
      else
      {
        Serial.print("M");
      }
      break;
    case readTemperature:
      Serial.print("T");
      if(temperature < 100) Serial.print("0"); // take care of leading zeros
      if(temperature < 10) Serial.print("0");
      if(temperature < 0)
      {
        Serial.print(".00");  // This shouldn't happen but just in case...
      }
      else
      {
        Serial.print(temperature,2);
      }
      break;
    case setHeater:
    case readHeater:
      Serial.print("H");
      if(heater < 100) Serial.print("0"); // take care of leading zeros
      if(heater < 10) Serial.print("0");    
      Serial.print((double)heater,0);
      break;  
    case setFan:
    case readFan:
      Serial.print("F");
      if(fan < 100) Serial.print("0"); // take care of leading zeros
      if(fan < 10) Serial.print("0");    
      Serial.print((double)fan,0);
      break; 
    case setDrum:
    case readDrum:
      if(drumMotor == on)
      {
        Serial.print("+");
      }
      else
      {
        Serial.print("-");
      }
      break;
    case setCaseFan:
    case readCaseFan:
      if(caseFan == on)
      {
        Serial.print("^");
      }
      else
      {
        Serial.print("#");
      }
      break;      
    default:
      Serial.print("U");  // Unknown command
      break;
  }
  Serial.print("/");  // Send end character
}

void setFrontPanelLEDs()
{
  switch(controlMode)
  {
    case computer:
      digitalWrite(MANUAL_LED_OUTPUT, LOW);
      digitalWrite(COMPUTER_LED_OUTPUT, HIGH);
      break;
    case manual:
      digitalWrite(MANUAL_LED_OUTPUT, HIGH);
      digitalWrite(COMPUTER_LED_OUTPUT, LOW);
      break;
  }
}

//*****************************************************************
// LCD display code
//*****************************************************************

// The default I2C slave address for the display is 50 hex
// The Wire library uses 7-bit addresses so we need to right-shift
// by one bit to get the correct address
#define DISPLAY_I2C_ADDRESS  0x50>>1

// The command prefix for the display - send this byte
// followed by the command
#define DISPLAY_COMMAND_PREFIX 0xFE

// Command codes for the display
#define DISPLAY_ON 0x41
#define DISPLAY_CURSOR_POS 0x45
#define DISPLAY_CURSOR_HOME 0x46
#define DISPLAY_CLEAR_SCREEN 0x51
#define DISPLAY_SET_BRIGHTNESS 0x53

// Display brightness can be set from 1-8
#define DISPLAY_BRIGHTNESS 8

void initializeDisplay()
{
  // start the I2C display interface
  pinMode(I2C_SDA, OUTPUT);
  pinMode(I2C_CLK, OUTPUT);
  Wire.begin();
  
  // Put something on the display
  Wire.beginTransmission(DISPLAY_I2C_ADDRESS);
  Wire.write(DISPLAY_COMMAND_PREFIX);
  Wire.write(DISPLAY_ON);
  Wire.write(DISPLAY_COMMAND_PREFIX);
  Wire.write(DISPLAY_SET_BRIGHTNESS);
  Wire.write(DISPLAY_BRIGHTNESS);
  Wire.write(DISPLAY_COMMAND_PREFIX);
  Wire.write(DISPLAY_CLEAR_SCREEN);
  Wire.endTransmission();
  Wire.beginTransmission(DISPLAY_I2C_ADDRESS);
  Wire.write("    NSE Labs");
  Wire.write(DISPLAY_COMMAND_PREFIX);
  Wire.write(DISPLAY_CURSOR_POS);
  Wire.write(0x40); // Beginning of second line
  Wire.write(" Tissot Coffee");
  Wire.endTransmission();
}

void updateDisplay()
{
  double tempF; // temperature in degrees
  char firstLine[17]; //16 chars per line plus null terminator
  char secondLine[17];
  PString line1(firstLine, sizeof(firstLine));
  PString line2(secondLine, sizeof(secondLine));
  
  tempF = temperature * 9.0/5.0 + 32;
  
  line1.print("HTR ");
  line1.print(heater);
  line1.print("% ");
  if(heater<100) line1.print(" ");
  if(heater<10) line1.print(" ");
  if(tempF<100.0) line1.print(" ");
  line1.print(tempF,1);
  line1.print("\xDF"); // degree symbol
  line1.print("F");

  
  line2.print("FAN ");
  line2.print(fan);
  line2.print("% ");
  if(fan<100) line2.print(" ");
  if(fan<10) line2.print(" ");
  if(controlMode == computer)
  {
    line2.print("   Auto");
  }
  {
    line2.print(" Manual");
  }
  

  Wire.beginTransmission(DISPLAY_I2C_ADDRESS);
  Wire.write(DISPLAY_COMMAND_PREFIX);
  Wire.write(DISPLAY_CURSOR_HOME);
  Wire.write(firstLine);
  Wire.endTransmission();
 
  Wire.beginTransmission(DISPLAY_I2C_ADDRESS);
  Wire.write(DISPLAY_COMMAND_PREFIX);
  Wire.write(DISPLAY_CURSOR_POS);
  Wire.write(0x40); // Beginning of second line
  Wire.write(secondLine);
  Wire.endTransmission();
  
}

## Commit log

2023-01-12 Create Hardware Pin Assignments.md
2023-01-12 Update Hardware Pin Assignments.md
2023-01-17 Initial version of small display cover
    [Small Display Cover-Body.stl, Small Display Cover.FCStd]
2023-01-17 Small display cover v2
    Adjusted dimensions
    [Small Display Cover-Body.stl, Small Display Cover.FCStd]
2023-01-17 Small Display Cover V3
    [Small Display Cover-Body.stl, Small Display Cover.FCStd]
2023-01-20 Initial large display enclosure
    [Large Display Mount Bottom-Body.stl, Large Display Mount Bottom.FCStd]
2023-01-23 Add drawings
    Added test design for large display bottom and drawings for the base and small display cover.
    [Large Display Mount Base-Body.stl, Large Display Mount Base.FCStd, Large Display Mount Bottom-Body.stl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]
2023-01-23 Large Display Bottom Test #2
    [Large Display Mount Bottom-Body.stl, Large Display Mount Bottom.FCStd]
2023-01-25 Added bottom of display mount
    [Large Display Mount Bottom-Body.stl, Large Display Mount Bottom.FCStd, Large Display Mount-Body.stl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]
2023-01-25 Drawings for large display mount
    [Large Display Mount.FCStd]
2023-02-03 Updated large display mount
    [AC Inlet Backing Plate-Body.stl, AC Inlet Backing Plate.FCStd, Large Display Mount-Body.stl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]
2023-02-03 Added hole cover design
    [Hole Cover-Nut.stl, Hole Cover-Screw.stl, Hole Cover.FCStd]
2023-02-04 Updated large display base
    [Large Display Mount Base-Body.stl, Large Display Mount Base.FCStd]
2023-02-05 Updated large display enclosure
    [Large Display Mount-Front Face.stl, Large Display Mount.FCStd]
2023-02-09 updated mechanical designs
    [Cable clamp washer-Body.stl, Cable clamp washer.FCStd, Large Display Mount-Body.stl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]
2023-02-09 Update Serial Protocol.md
    Add commands for drum motor and case fan
2023-02-09 Update Protocol State Machine.md
    Updated to include new drum motor and case fan commands
2023-02-10 Correct Fan/Heater pins
2023-02-10 Roaster fan now working
2023-02-11 Added new serial commands
    Added serial commands to set and read drum motor and case fan
2023-02-13 Create Fan Control Code Design.md
2023-02-13 Update Fan Control Code Design.md
2023-02-14 Update Roaster_V2.ino
    Pull out code that controls the heater triac since this will now be controlled by a solid state relay. Leave the code that controls the fan triac.
2023-02-14 Update Roaster_V2.ino
    Heater control implemented
2023-02-20 Update Roaster_V2.ino
    Turn on drum motor if heater control is turned above 2%.
2023-02-22 Added PID tuning trial
    Tuning seems pretty good
2023-02-28 Added hardware documentation
    [CoffeeRoasterV2.kicad_pcb, CoffeeRoasterV2.kicad_sch]
2023-02-28 Updated hardware documentation
    [CoffeeRoasterV2.kicad_sch]
2023-03-02 Circuit correction
    Corrected LED resistor values on front panel interface board.
    [CoffeeRoasterV2.kicad_sch]
